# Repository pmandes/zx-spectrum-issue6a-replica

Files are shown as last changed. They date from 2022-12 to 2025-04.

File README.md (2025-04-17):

# ZX Spectrum 48k Issue 6A board replica

This is PCB replica of the motherboard of a ZX Spectrum 48k 8-bit computer. It was created on the basis of the last version of the board - "ISSUE 6A" - which was mounted in both Spectrum 48k and Spectrum+. It differs from previous versions mainly by integrating the logic and memory multiplexers in one ZX8401 chip, as well as an improved (especially in comparison with the first versions) the power supply circuit.

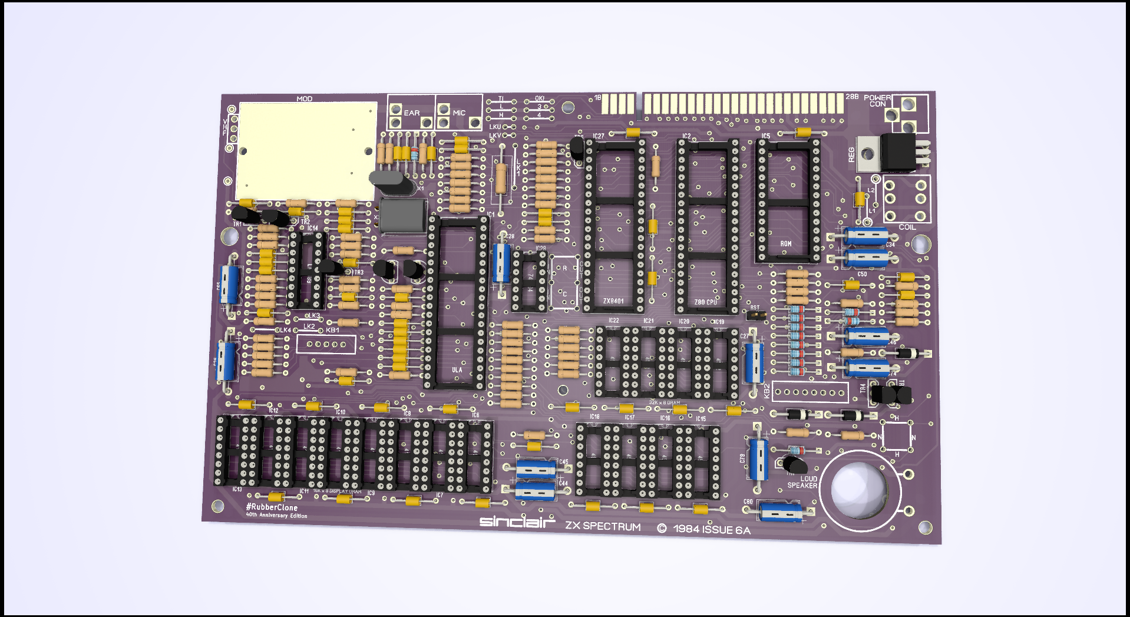
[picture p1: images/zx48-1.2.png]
ISSUE 6A motherboard


## The purpose of the project

I created it as a tribute to this wonderful little computer for the 40th anniversary of its creation, which for many of us started the adventure in the world of IT technology. Thanks to this replica, you can repair your old ZX Spectrum in which the connector contacts have worn off, tracks and pads have torn off after numerous repairs or have simply been destroyed by rust. After transplanting components to a new board, your Spectrum will not only gain a new life, but also a great look.

### The ISSUE 6A board requires the following components:

- Zilog Z80 processor
- ZX8401 / PCF1306P chip - or its cheap direct replacement built on SMD 74LS chips
- ULA in any version (originally on this board was Ferranti 6C001E-7) or a perfect, modern replacement vLA82
- original ZX Spectrum ROM or EPROM 27C256/27C512 with programmed BASIC binary (requires a slight modification or adapter, e.g. [ZXROM 4-in-1](https://github.com/pmandes/zx-spectrum-issue6a-replica/tree/main/ZX-ROM-4-in-1))
- lower memory chips type 4116 (e.g. TMS4116-15NL, STC 4116-2N) or a modern SRAM replacement board
- upper memory chips type 4532 or compatible (e.g. TMS 4532-20NL4, OKI M3764-20RS) or modern SRAM module
- LM1889 video modulation chip
- UM1233 RF modulator or S-VIDEO mod board or simple composite output mod

## BOM:

https://docs.google.com/spreadsheets/d/1GlukvK-rJ6DSs6qOmtWpRyai1MQ1hy25GcS9ePSdg4E/edit?usp=sharing

- The resistor and capacitor values in the BOM file are for Ferranti ULA
- For a standard Ferranti ULA - **do not populate: R90, C100, C102, C103**, leave LK1, LK2, LK3, LK4 - opened
- For SAGA chip - refer the Service Manual
- For TMS chips on upper memory: TI - close, 3 or 4 - depends on the marking on the chip: i.e. TMS4532-20NL**4**
- For OKI chip on upper memory: OKI - close, L or H - depends on the marking on the chip: i.e. OKI3732**L**-20RS, for OKI3764 - you can choose which 'half' of its 64kbit you want to use
- ROM settings: N - close for NEC chips, H - for HITACHI chips, for the EPROM adapter - it does not matter

**Correct jumper configuration near IC28:**

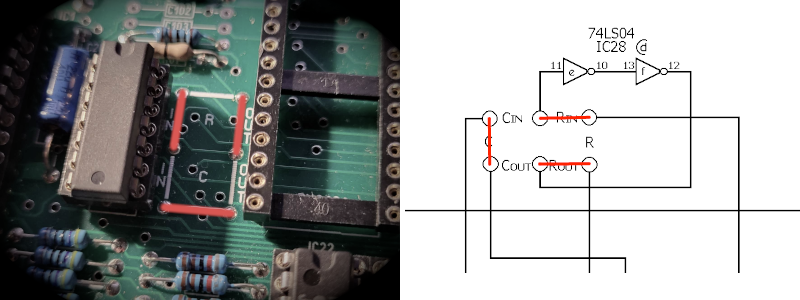
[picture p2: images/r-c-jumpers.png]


**Interactive BOM:**
<p align="center"><a href="https://htmlpreview.github.io/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
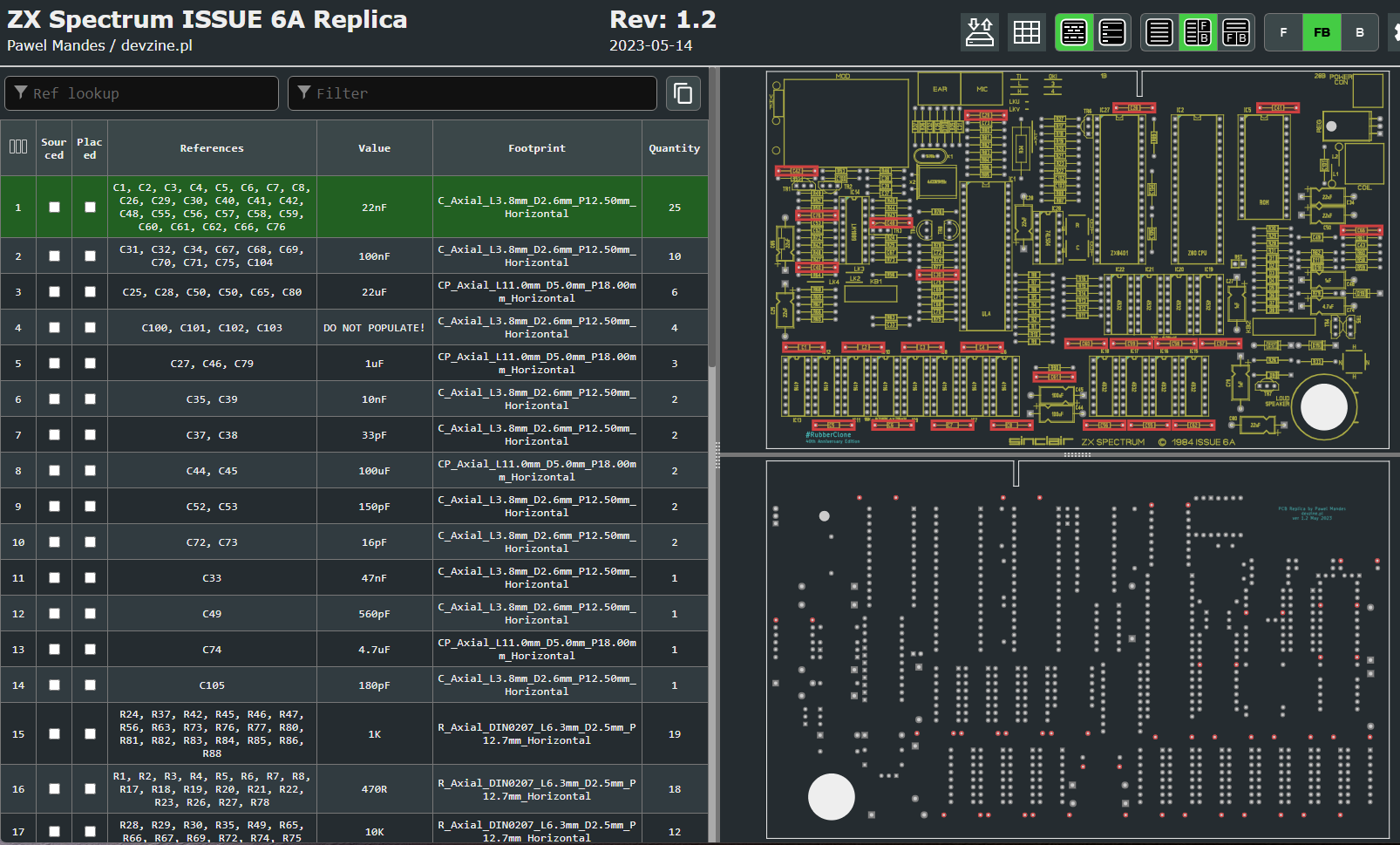
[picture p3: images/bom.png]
"></a></p>

**Notice:**

I received reports that the board version 1.1 (Dec 2022) has too small holes for the original **BA157** diodes (D15 and D17) - I used **BA159** diodes manufactured by **MIC** in the DO-41 package. They have 0.55mm / 0.0215inch thick legs - they fit and work perfectly.

## Motherboard layout:
https://github.com/pmandes/zx-spectrum-issue6a-replica/blob/main/Issue-6A-layout.pdf
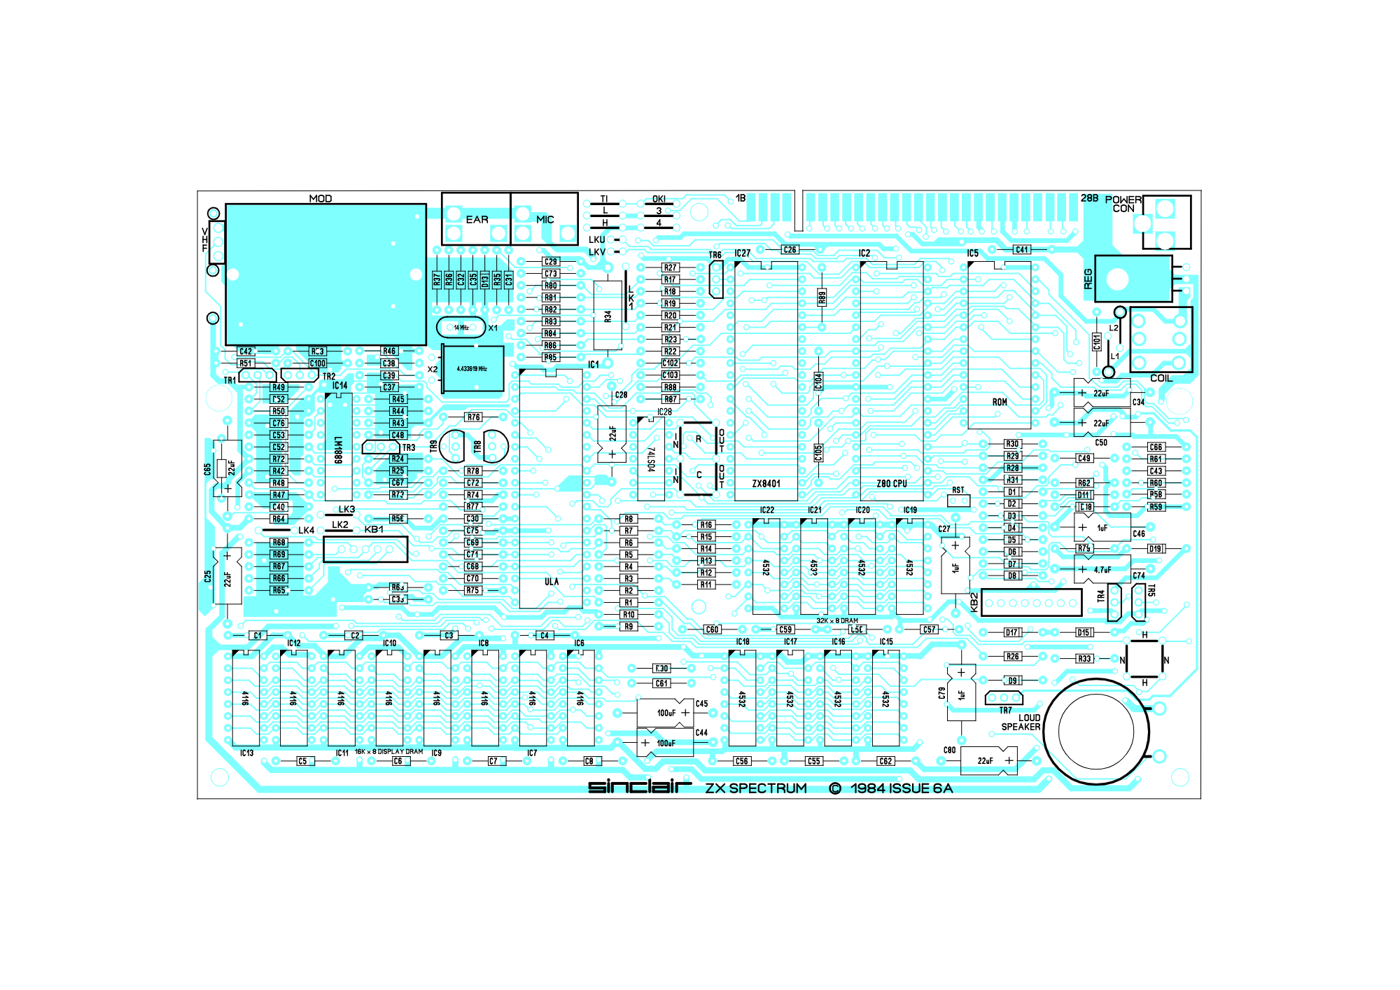
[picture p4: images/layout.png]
Motherboard layout

## Changelog:

**1.2**
- enlargement of all solder holes up to 0.8mm, holes for D15/D17 diodes up to 1mm

**1.1**
- improving the position of the mounting holes
- correction of all mistakes detected on the prototype

**1.0**
- prototype

## PCBs:

Here you can order ready-made, unpopulated PCBs:

https://www.tindie.com/products/devzine_pl/zx-spectrum-48k-issue-6a-motherboard-replica-pcbs/

## ROMs:

- https://mdfs.net/Software/Spectrum/ROMImages/
- https://github.com/brendanalford/zx-diagnostics
- http://blog.retroleum.co.uk/electronics-articles/a-diagnostic-rom-image-for-the-zx-spectrum/

## Alternative components:

- PCF1306P / ZX8401: https://trastero.speccy.org/cosas/JL/pcf1306p/PCF1306P.html
- PCF1306P SMD: https://www.va-de-retro.com/foros/viewtopic.php?p=182085#p182085
- S-Video Mod: https://github.com/redhawk668/ZX-Spectrum-S-Video
- Composite Mod: https://www.projectavr.com/esp-01-esp-03-flash-prototyping-board/

## Useful resources:
- Schematics: https://spectrumforeveryone.com/technical/zx-spectrum-pcb-schematics-layout/
- Service manual: https://spectrumforeveryone.com/wp-content/uploads/2017/08/ZX-Spectrum-Service-Manual.pdf
 
---

All material published here is under a [Creative Commons 4.0 license](https://creativecommons.org/licenses/by-nc-nd/4.0/).



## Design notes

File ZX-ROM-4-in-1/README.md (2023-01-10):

# ZXROM 4-in-1
## 27C512 EPROM adapter for ZX Spectrum 48K

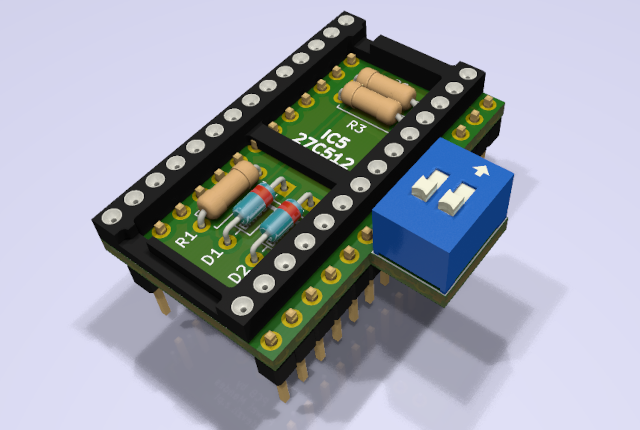
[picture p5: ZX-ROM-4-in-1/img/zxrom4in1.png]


### Bill of materials:

<p align="center">
<a href="https://htmlpreview.github.io/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
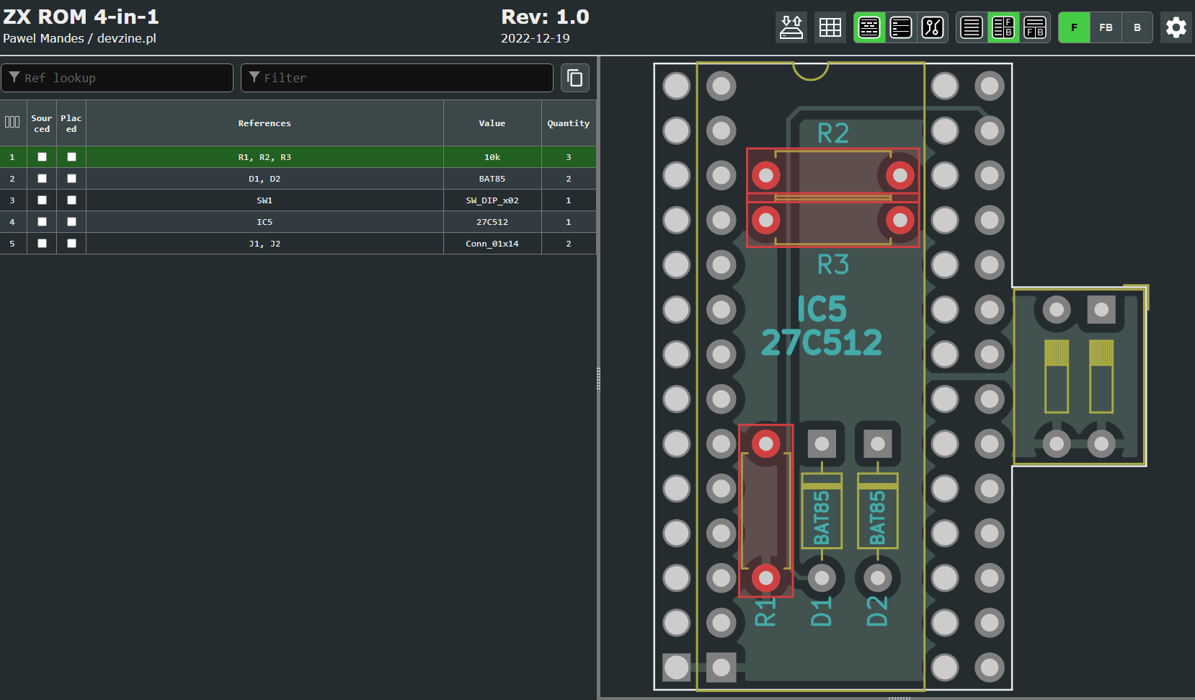
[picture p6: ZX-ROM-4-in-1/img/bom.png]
"></a>
</p>

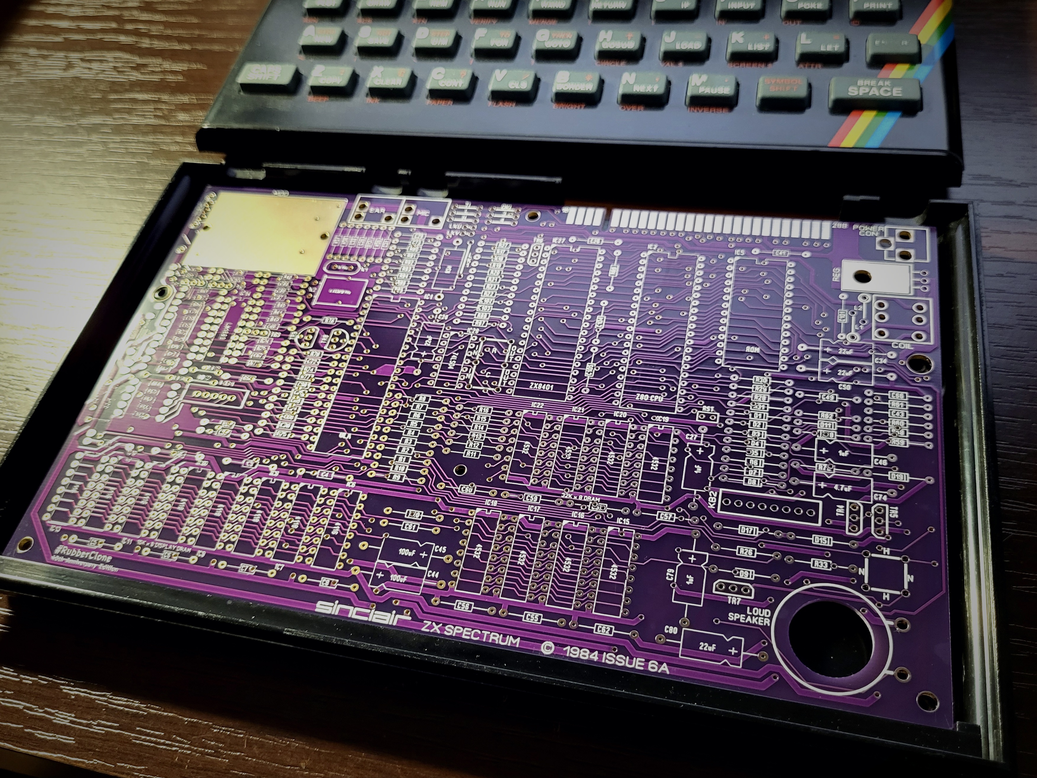
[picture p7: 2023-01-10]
images/v1.1-3.jpg

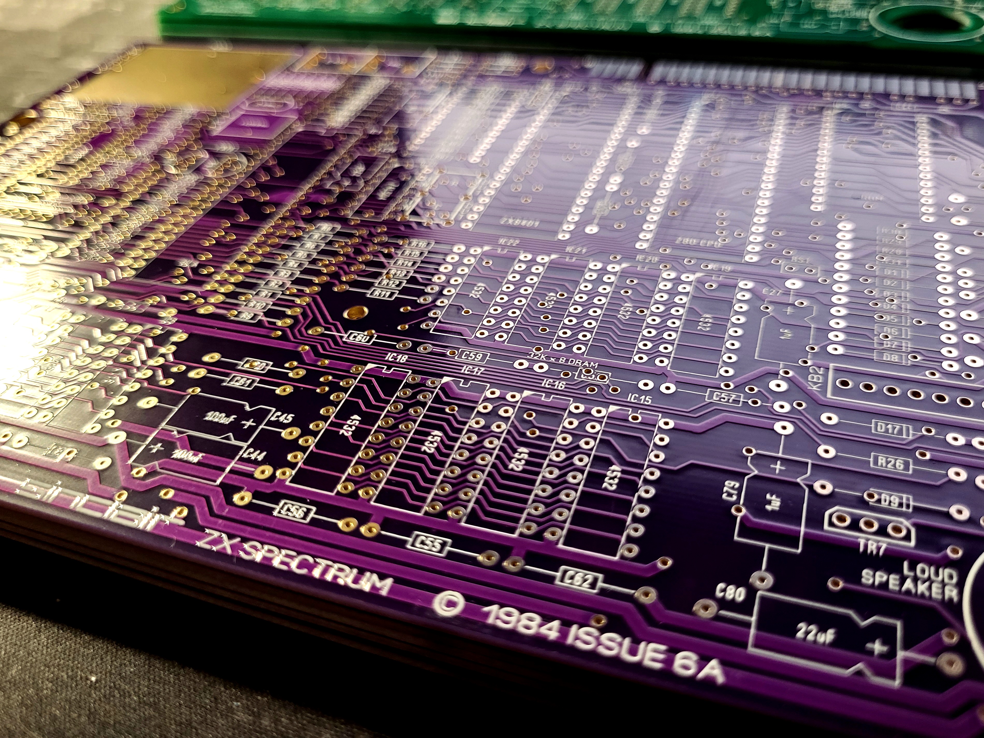
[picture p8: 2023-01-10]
images/v1.1-2.jpg

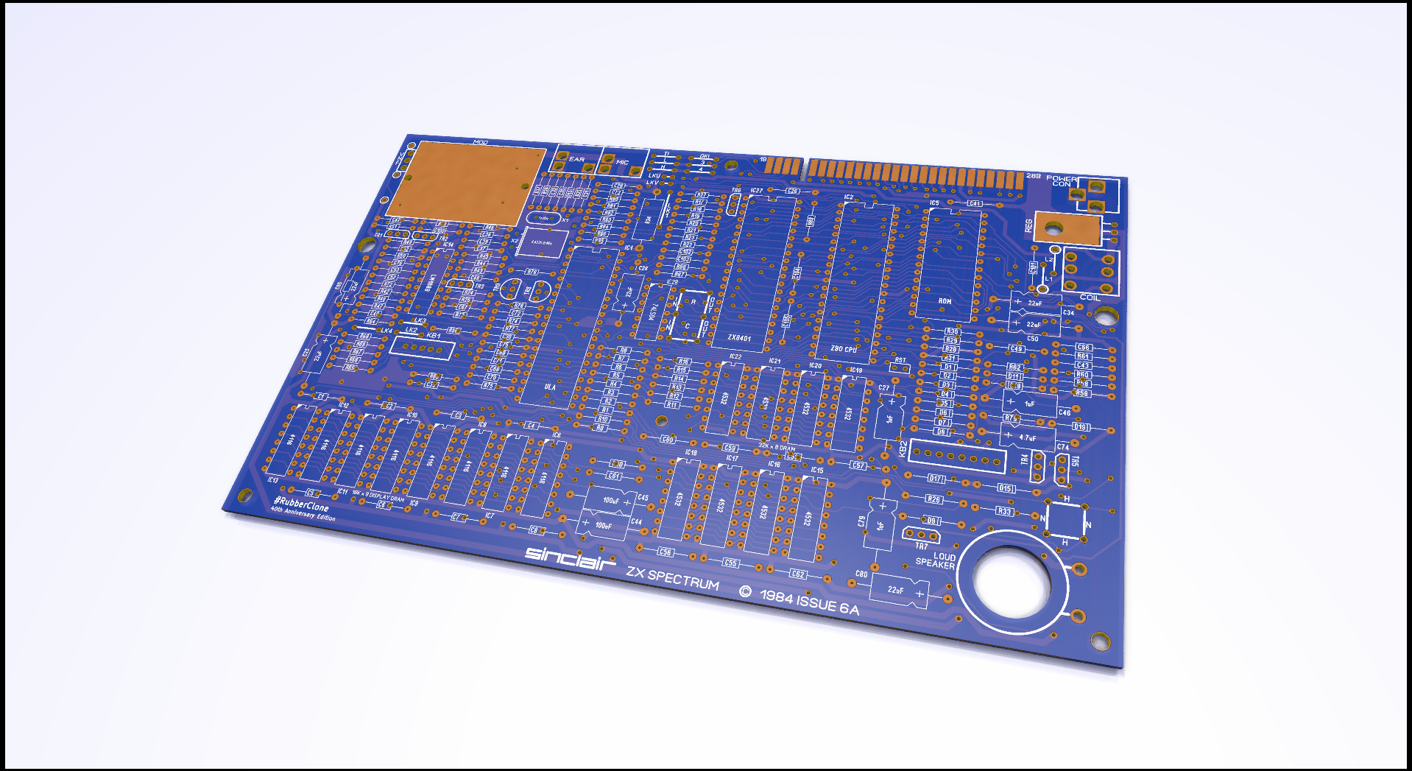
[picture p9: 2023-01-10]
images/zx48-1.1.png

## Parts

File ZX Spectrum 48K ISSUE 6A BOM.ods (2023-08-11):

Got it | Ref | Value | Rating, Tol | Type
 | CAPACITORS
 | C25,C28,C34,C50,C65,C80 | 22uF | 16V | Electrolytic | 6
 | C27,C46,C79 | 1uF | 50V | Electrolytic | 3
 | C44,C45 | 100uF | 16V | Electrolytic | 2
 | C74 | 4.7uF | 25V | Electrolytic | 1
 | C1,C2,C3,C4,C5,C6,C7,C8,C26,C29,C30,C40,C41,C42,C48,C55,C56,C57,C58,C59,C60,C61,C62,C66,C76,C101 | 22nF | 25V, 10% | Ceramic | 25
 | C31,C32,C43,C67,C68,C69,C70,C71,C75,C104 | 100nF | 25V, 10% | Ceramic | 10
 | C33 | 47nF | 25V, 10% | Ceramic | 1
 | C35,C39,C100 | 10nF | 25V, 10% | Ceramic | 3
 | C37,C38 | 33pF | 25V, 10% | Ceramic | 2
 | C49 | 560pF | 25V, 10% | Ceramic | 1
 | C52,C53 | 150pF | 25V, 10% | Ceramic | 2
 | C72,C73 | 16pF | 25V, 5% | Ceramic | 2
 | C105 | 180pF | 25V, 10% | Ceramic | 1
 | CRYSTALS
 | X1 | 14 MHz |  |  | 1
 | X2 | 4.43361875 MHz |  |  | 1
 | TRANSISTORS
 | TR1,TR2,TR3,TR6 | ZTX313 / MPS2369 |  |  | 4
 | TR4 | ZTX651 (ZTX650) |  |  | 1
 | TR5 | ZTX751 (ZTX213) |  |  | 1
 | TR7 | ZTX450 |  |  | 1
 | TR8,TR9 | BC184 |  |  | 2
 | DIODES
 | D1-D9,D11,D13,D18 | 1N4148 |  | Signal | 11
 | D15,D17 | BA157 |  | Rectified | 2 | I received reports that the board version 1.1 (Dec 2022) has too small holes for the original BA157 diodes (D15 and D17) - I used BA159 diodes manufactured by MIC in the DO-41 package. They have 0.55mm / 0.0215inch thick legs - they fit and work perfectly.
 | D19 | BZY88C | 5,1V 0.5W | Zener 5.1V | 1
 | RESISTORS
 | R1,R2,R3,R4,R5,R6,R7,R8,R17,R18,R19,R20,R21,R22,R23,R26,R27,R78 | 470R |  |  | 18
 | R9,R10,R11,R12,R13,R14,R15,R16,R89 | 8K2 |  |  | 9
 | R24,R37,R42,R45,R46,R47,R56,R63,R73,R76,R77,R80,R81,R82,R83,R84,R85,R86,R88 | 1K |  |  | 19
 | R25 | 180R |  |  | 1
 | R28,R29,R30,R35,R49,R65,R66,R67,R69,R72,R74,R75 | 10K |  |  | 12
 | R31 | 220K |  |  | 1
 | R33 | 680R/560R |  |  | 1
 | R36 | 680R |  |  | 1
 | R34 | 15R | 1W |  | 1
 | R43 | 3K | 2% |  | 1
 | R44 | 5K1 | 2% |  | 1
 | R48,R51,R52,R79 | 2K2 |  |  | 4
 | R50 | 4K7 |  |  | 1
 | R53 | 390R |  |  | 1
 | R58 | 1K | 2% |  | 1
 | R59 | 1K8 | 2% |  | 1
 | R60 | 220R |  |  | 1
 | R61,R62,R64 | 15R |  |  | 3
 | R68 | 6K8 |  |  | 1
 | R87 | 0R |  |  | 1
 | R90 | 2K7 | do not populate! |  | 1
 | INTEGRATED CIRCUITS |  |  |  |  | Alternatives:
 | IC1 | 6C001E-7 | Ferranti | ULA | 1
 | IC2 | Z80A | NEC/Zilog | CPU | 1
 | IC5 | 23128 | NEC/Hitachi | ROM | 1 | 27C256 EPROM | https://spectrumforeveryone.com/technical/fitting-eprom-48k-spectrum/ http://blog.retroleum.co.uk/electronics-articles/how-to-replace-the-rom-of-a-zx-spectrum-with-an-eprom/
 | IC6-IC13 | 4116 | 150ns | Display RAM | 8
 | IC14 | LM1889 | National | TV Video | 1
 | IC15-IC22 | 4532 | Texas/OKI | Upper RAM | 8
 | IC27 | ZX8401 | Mullard | Logic | 1 | ZXMUX / PCF1306P | https://8bit.yarek.pl/upgrade/zx.zxmux/index.html https://trastero.speccy.org/cosas/JL/pcf1306p/PCF1306P.html https://www.va-de-retro.com/foros/viewtopic.php?p=182085#p182085
 | IC28 | 74LS04 | Texas | 6 x Inverter | 1
 | SOCKETS
 | IC1, IC2, IC27 | 40pin |  |  | 3
 | IC5 | 28pin |  |  | 1
 | IC6-IC13,IC15-IC22 | 16pin |  |  | 16
 | IC14 | 18pin |  |  | 1
 | IC28 | 14pin |  |  | 1
 | CONNECTORS
 | EAR |  |  | 3.5mm jack socket | 1
 | MIC |  |  | 3.5mm jack socket | 1
 | PWR |  |  | 2.1mm co-axial socket | 1
 | KB1 | Molex 5229-05CPB |  | 5-way ribbon connector | 1
 | KB2 | Molex 5229-08CPB |  | 8-way ribbon connector | 1
 | MISCELLANEOUS |  |  |  |  | Alternatives:
 | COIL L1-L2 | 13/39 | N. Devon | 2 windings on toroidal former | 1
 | REG | 7805 |  | 5V regulator | 1 | Murata OKI-78SR-5/1.5-W36-C | https://www.conrad.pl/p/przetwornica-dcdc-do-pcb-murata-power-solutions-oki-78sr-515-w36-c-15-a-75-w-ilosc-wyjsc-1-x-1536481
 | MOD | UM1233 | Astec | UHF modulator | 1 | SVIDEO Mod: Composite Mod: | https://github.com/redhawk668/ZX-Spectrum-S-Video https://www.projectavr.com/esp-01-esp-03-flash-prototyping-board/
 | LOUD SPEAKER | 40 ohm / 23mm | G. English (Merry) |  | 1

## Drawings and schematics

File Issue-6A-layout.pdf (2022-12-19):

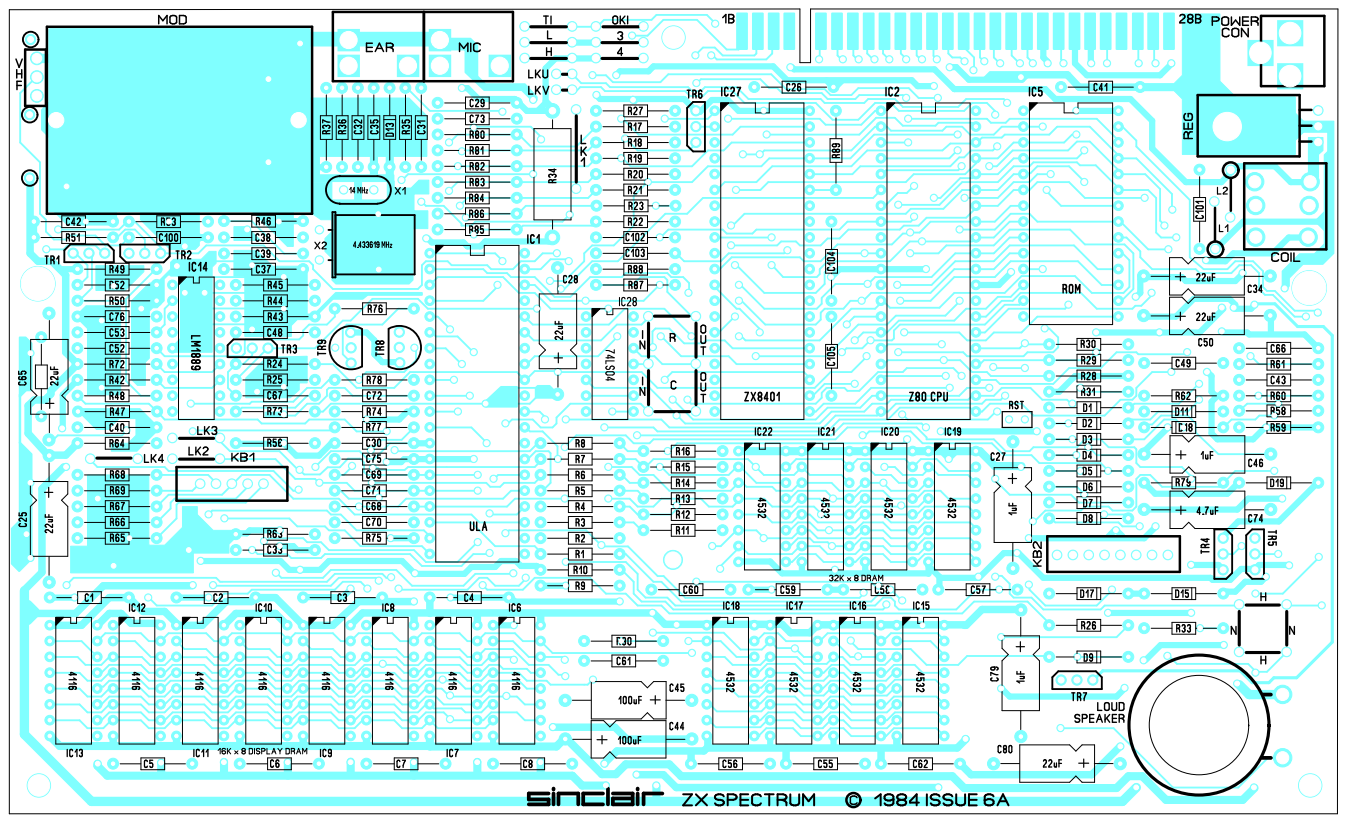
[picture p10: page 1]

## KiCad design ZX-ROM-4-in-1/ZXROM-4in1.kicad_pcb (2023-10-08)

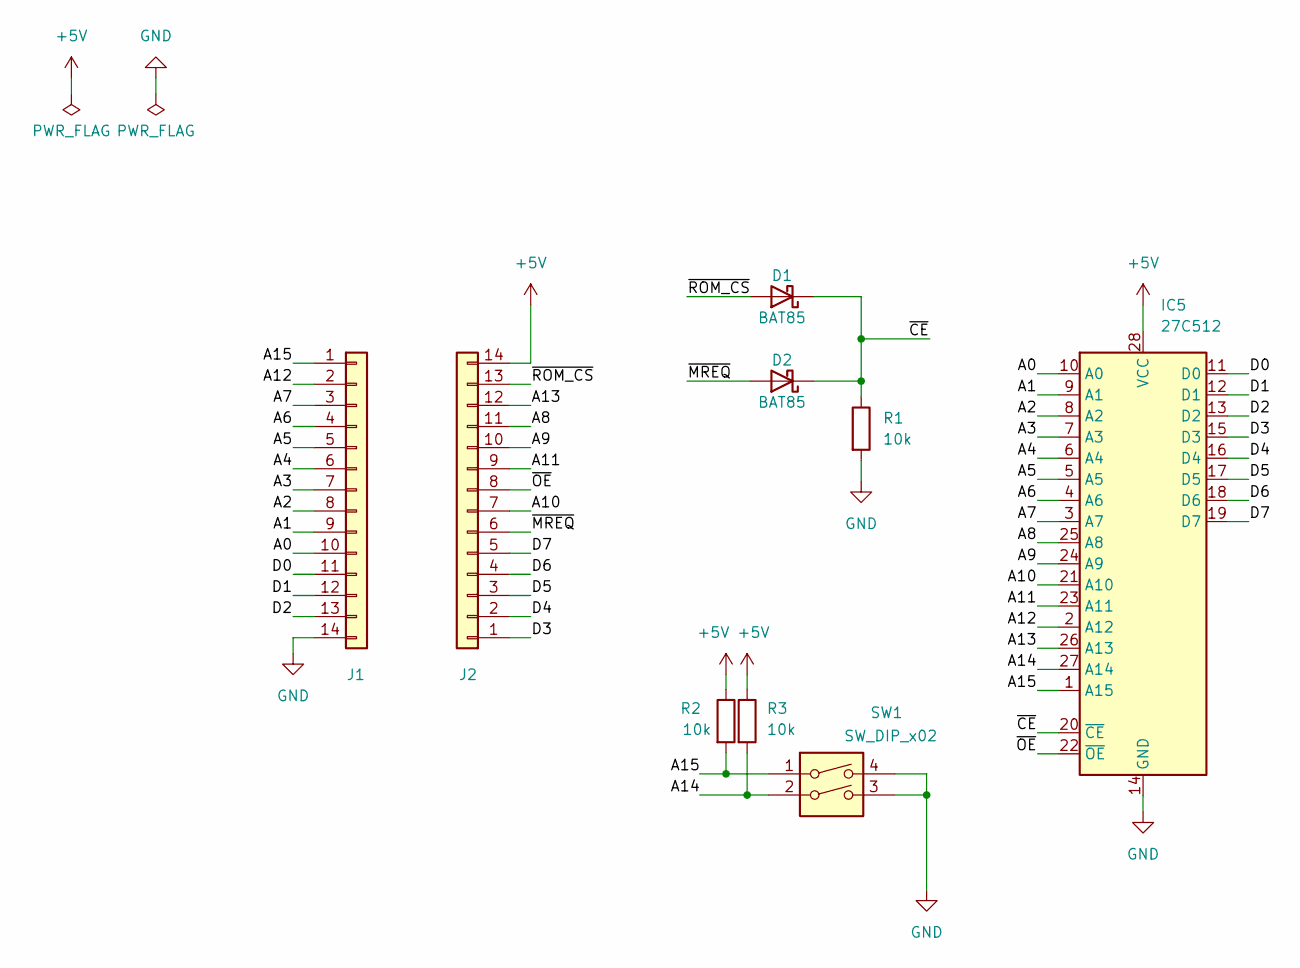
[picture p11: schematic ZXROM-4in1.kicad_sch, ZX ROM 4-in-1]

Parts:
D1, D2: BAT85; D_DO-35_SOD27_P7.62mm_Horizontal
IC5: 27C512; DIP-28_W15.24mm
J1, J2: Conn_01x14; PinHeader_1x14_P2.54mm_Vertical
R1, R2, R3: 10k; R_Axial_DIN0207_L6.3mm_D2.5mm_P7.62mm_Horizontal
SW1: SW_DIP_x02; SW_DIP_SPSTx02_Slide_9.78x7.26mm_W7.62mm_P2.54mm

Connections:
+5V: IC5.28 (VCC), J2.14, R2.1, R3.1
/A0: IC5.10 (A0), J1.10
/A1: IC5.9 (A1), J1.9
/A2: IC5.8 (A2), J1.8
/A3: IC5.7 (A3), J1.7
/A4: IC5.6 (A4), J1.6
/A5: IC5.5 (A5), J1.5
/A6: IC5.4 (A6), J1.4
/A7: IC5.3 (A7), J1.3
/A8: IC5.25 (A8), J2.11
/A9: IC5.24 (A9), J2.10
/A10: IC5.21 (A10), J2.7
/A11: IC5.23 (A11), J2.9
/A12: IC5.2 (A12), J1.2
/A13: IC5.26 (A13), J2.12
/A14: IC5.27 (A14), R3.2, SW1.2
/A15: IC5.1 (A15), J1.1, R2.2, SW1.1
/D0: IC5.11 (D0), J1.11
/D1: IC5.12 (D1), J1.12
/D2: IC5.13 (D2), J1.13
/D3: IC5.15 (D3), J2.1
/D4: IC5.16 (D4), J2.2
/D5: IC5.17 (D5), J2.3
/D6: IC5.18 (D6), J2.4
/D7: IC5.19 (D7), J2.5
/~CE: D1.1 (K), D2.1 (K), IC5.20 (~CE), R1.1
/~MREQ: D2.2 (A), J2.6
/~OE: IC5.22 (~OE), J2.8
/~ROM_CS: D1.2 (A), J2.13
GND: IC5.14 (GND), J1.14, R1.2, SW1.3, SW1.4

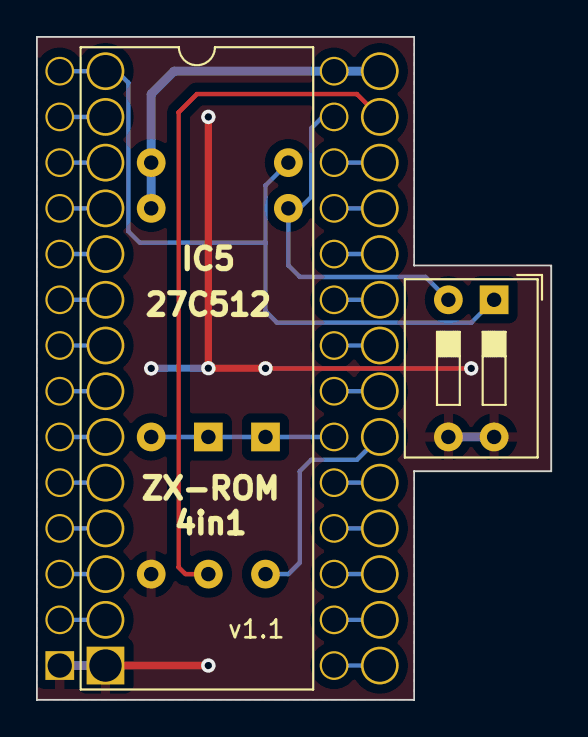
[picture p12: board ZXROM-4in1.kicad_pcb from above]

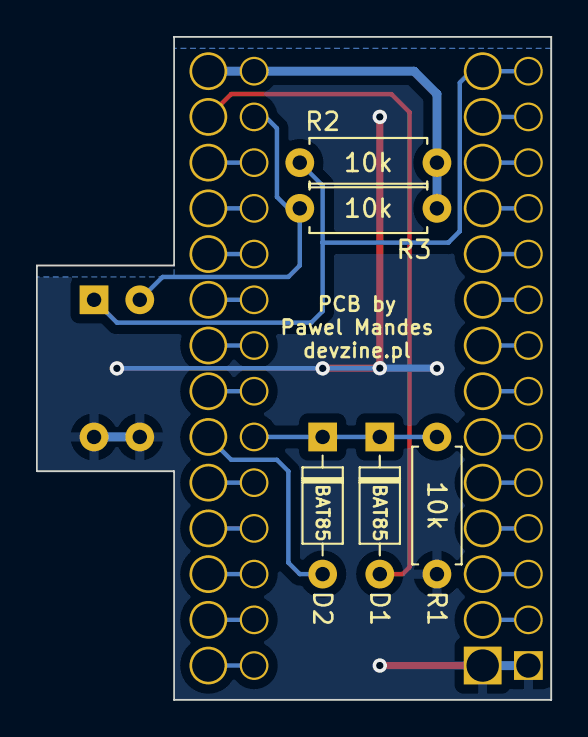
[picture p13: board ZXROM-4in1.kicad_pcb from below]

Board: 2 copper layers, 28.6 x 36.8 mm, 9 parts (5 on the bottom side), 30 nets.

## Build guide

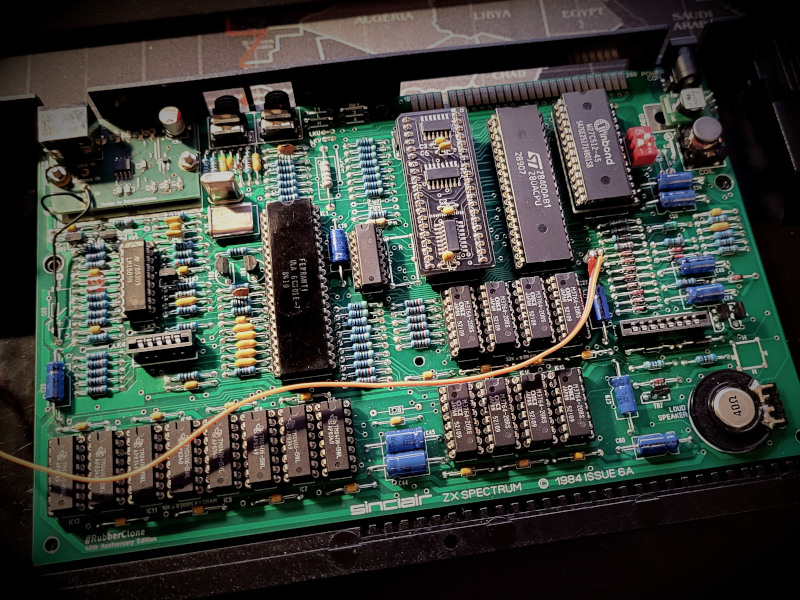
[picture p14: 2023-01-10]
images/assembled.jpg

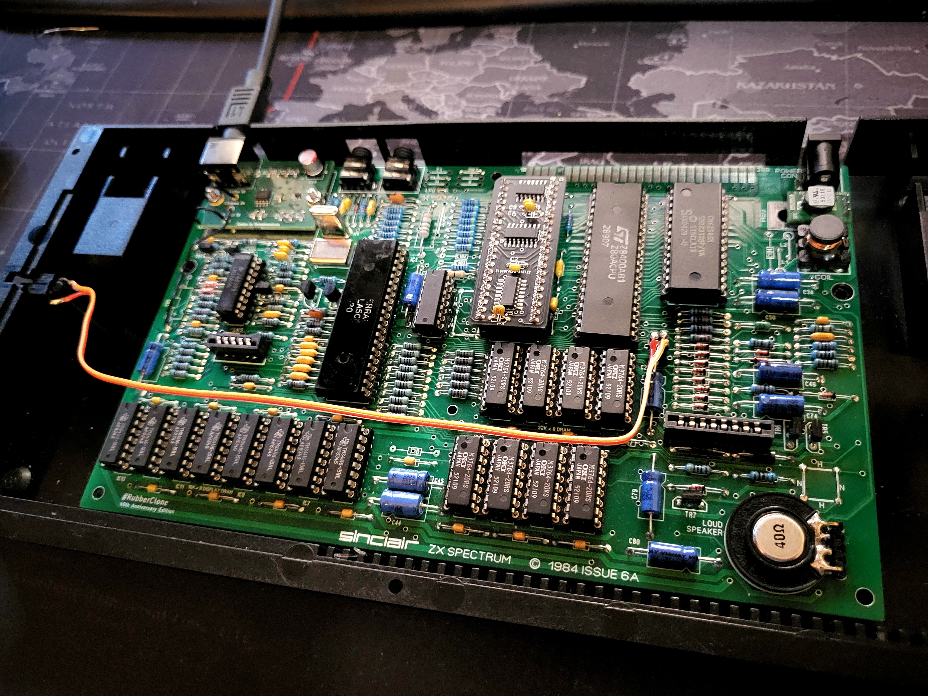
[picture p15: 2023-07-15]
images/assembled4.jpg

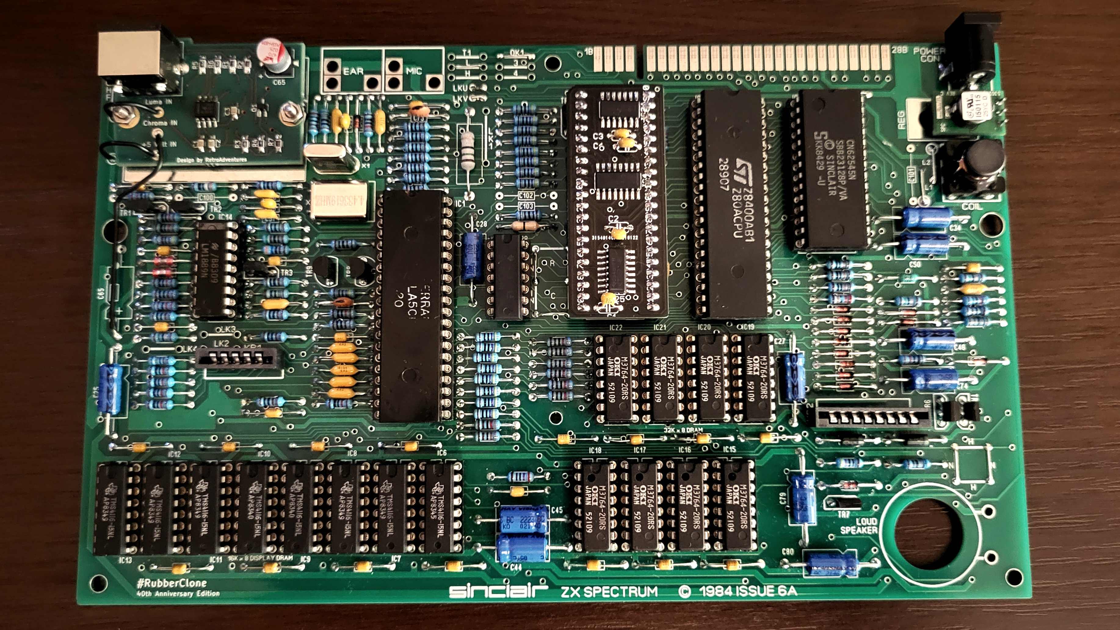
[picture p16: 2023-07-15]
images/assembled3.jpg

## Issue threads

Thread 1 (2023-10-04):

Use in real ZX Spectrum 48K

IgnacioMonge, 2023-10-04:
Hi Pavel,

I love this PCB for EPROM.
I'm planning to build it for my ZX48K, but I'm not sure it can be used without any modification to the actual ZX.
I know that using EPROM requires some modifications.,

Thank you in advance!

Best,
Ignacio

pmandes, 2023-10-04:
Hi.

If you want to use the adapter, you don't need to modify anything on the ZX Spectrum board.
That is what it was created for :)

Pawel

pmandes, 2023-10-04:
Use version 1.1 from the KiCad project, not version 1.0. (In version 1.1, components are soldered on the underside to lower the structure). As a precaution, I will upload new gerbers tomorrow. The project itself is up to date.

userm8722, 2023-10-05:
HI, have the v1.1 gerbers been uploaded? Please advise I can't find them

userm8722, 2023-10-05:
regards

IgnacioMonge, 2023-10-06:
> Use version 1.1 from the KiCad project, not version 1.0. (In version 1.1, components are soldered on the underside to lower the structure). As a precaution, I will upload new gerbers tomorrow. The project itself is up to date.

Thank you, I have exported the gebers version 1.1 from the kicad project and order some pcbs. Awesome project!

userm8722, 2023-10-08:
hi where is the kicad project to export gerbers v1.1 please regards

IgnacioMonge, 2023-10-08:
The kicad project in the main github page are from 9 months ago. You should use these files.

userm8722, 2023-10-08:
Hi Thanks for reply. I don't know what i'm missing? The version is 1.0 not 1.1? Regards

IgnacioMonge, 2023-10-08:
Ok, let's do it easier.
* Download the whole project as a zip file (go to the green "Code" button on the github webpage).
* Unzip this file anywhere.
* Open Kicad (I'm using version 7)
*  Open the file "ZXROM-4in1.kicad_pro" inside the "zx-spectrum-issue6a-replica-main\ZX-ROM-4-in-1" folder.
*  If you open the "ZX-ROM-4-in-1.kicad_pcb" (left side) with the PCB editor and then open it on the 3D viever (Menú/View/3D Viewer), you will see that this is the actual 1.1 version.
* Now go to File\Fabrication Outputs and select Plot (say "refill" to the question). Then select "generate drill files".
* Put those files in the same directory and create a zip file with them.
* Now you have the 1.1 version.

userm8722, 2023-10-08:
Wow that's great. Thank you so much  Regards

pmandes, 2023-10-08:
Hello guys,

I've been busy with other things, but finally updated the project.
The gerber v1.1 files are already there. I'm glad you managed it :)

For future reference:
https://jlcpcb.com/help/article/362-how-to-generate-gerber-and-drill-files-in-kicad-7

exact instructions on how to generate yourself a gertber with the correct settings.

Best
Pawel

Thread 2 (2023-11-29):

BOM link not working

warrenstanley, 2023-11-29:
Hi - just a heads up, I seem to be having issues 8bit.yarek.pl. Tried using:

Microsoft Edge
Version 121.0.2220.3 (Official build) dev (64-bit)
Google Chrome
Version 119.0.6045.200 (Official Build) (64-bit)

The domains are probably outside your control, do you additional alternative sources?

pmandes, 2023-11-29:
It looks like Yarek's website is down.
You can find information about how it works
and how to make the ZX8401 (as well as all the files necessary for production) here:
https://trastero.speccy.org/cosas/JL/pcf1306p/PCF1306P.html

Closed 2023-11-29.

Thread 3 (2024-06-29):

D17 and D15 are the wrong footprint

lindoran, 2024-06-29:
Hello,

I just got to say this is quite an undertaking and I am happy somebody took the time to put this wonderful computer down in a replica PCB.  I was helping another member on the Spectrum For Everyone FB Group, who ran into this issue, It appears the footprint for D17 and D15 are actually DO-35 instead of DO-41.

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

as you can see the inside measurement of the through hole is .55 mm.

The MIC datasheet for the BA157 specifies the standard diameter of the pin (and footprint) as DO-41 which is .77 mm +/- .7mm (included below for your review)

I see you state in your live BOM that the BA157 from MIC fits -- I am wondering if that diode that you installed on yours is a mislabeled (or relabeled)  .5 amp fast recovery diode of some manufacture?  The interesting thing about that is - that most fast recovery DO-35 Diodes recover (significantly) faster than 1A diodes.  The minimum recovery time for the BA157 - 159 seems to be 500nS, as were most 1/2 Amp rectifiers recover much much faster.  A 1Kv .5A rectifier will also most likely perform just fine as a rectifier at 110Khz (if I recall correctly the speed of the oscillator in this particular inverter).  Additionally, if the board is built using a modern SRAM replacement for the lower 16K, or 5v Equivalents such as 4164 or 41256 the likelihood of the video amp even exceeding 200mA is low.  I did calculations on the 4116's a few weeks ago when I was rebuilding the DC-DC converter on my issue 4 -- the most the ram chips can draw functioning normally is 240mA.  The video amp is less than 100mA ... meaning the diodes in the circuit are oversized by ~50%.  That's not a bad thing and I would say its common practice in a power circuit to err on the side of caution always.

But in this case I think its most likely going to be well below oversized if only using 5v rail for the ram chips, and 12v for the Video amplifier.

At any rate.  I provide the footprint specifications below if you would like to update the footprint on your PCB.  And it might be prudent to update your live BOM.

Thanks for doing all the leg work on this wonderful PCB!  I think its great we can get a top masked PCB with the latest revison 48k Spectrum in 2024.

you can view the datasheet here:
[http://www.cnmic.com/DesktopModules/HT/BLOB/BA157%20THRU%20BA159.pdf](http://www.cnmic.com/DesktopModules/HT/BLOB/BA157%20THRU%20BA159.pdf)

You can view the DO-35 specification here:
[https://www.mouser.com/PCN/Microsemi_Corporation_DO_7_to_DO_35_customer_letter.pdf](https://www.mouser.com/PCN/Microsemi_Corporation_DO_7_to_DO_35_customer_letter.pdf)

and lastly the DO-41 specification here:
[https://www.diodes.com/assets/Package-Files/DO-41-Plastic.pdf](https://www.diodes.com/assets/Package-Files/DO-41-Plastic.pdf)

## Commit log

2022-12-19 ZXROM v1.0 initial commit, ISSUE 6A docs
    [ZX Spectrum 48K ISSUE 6A BOM.ods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]
2022-12-19 BOM for ZXROM
2023-01-10 New images, and adapter update
    [ZXROM-4in1.kicad_pcb]
2023-08-11 New pcb 3D render
2023-08-11 interactive BOM, and updated BOM file
    [ZX Spectrum 48K ISSUE 6A BOM.ods]
2023-08-11 bom image
2023-10-08 version 1.1
    [ZXROM-4in1-B_Cu.gbl, ZXROM-4in1-B_Mask.gbs, ZXROM-4in1-B_Paste.gbp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]
